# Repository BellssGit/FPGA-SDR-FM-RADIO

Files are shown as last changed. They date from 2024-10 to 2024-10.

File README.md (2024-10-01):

# FPGA-SDR-FM-RADIO
FPGA based FM radio with traditional IF architecture and digital IQ demodulation

[more detail (chinese only)](https://www.emoe.xyz/fpga_based_sdr_fm_radio/)

[demo video](https://www.bilibili.com/video/BV1SVxYeYEim/)

credit: https://github.com/alberto-grl/1bitSDR

Note； the PCB project name "R820T_With_LCMXO2" has nothing with R820T frontend IC, it was a thing when I start this PCB, but removed after few revisions.

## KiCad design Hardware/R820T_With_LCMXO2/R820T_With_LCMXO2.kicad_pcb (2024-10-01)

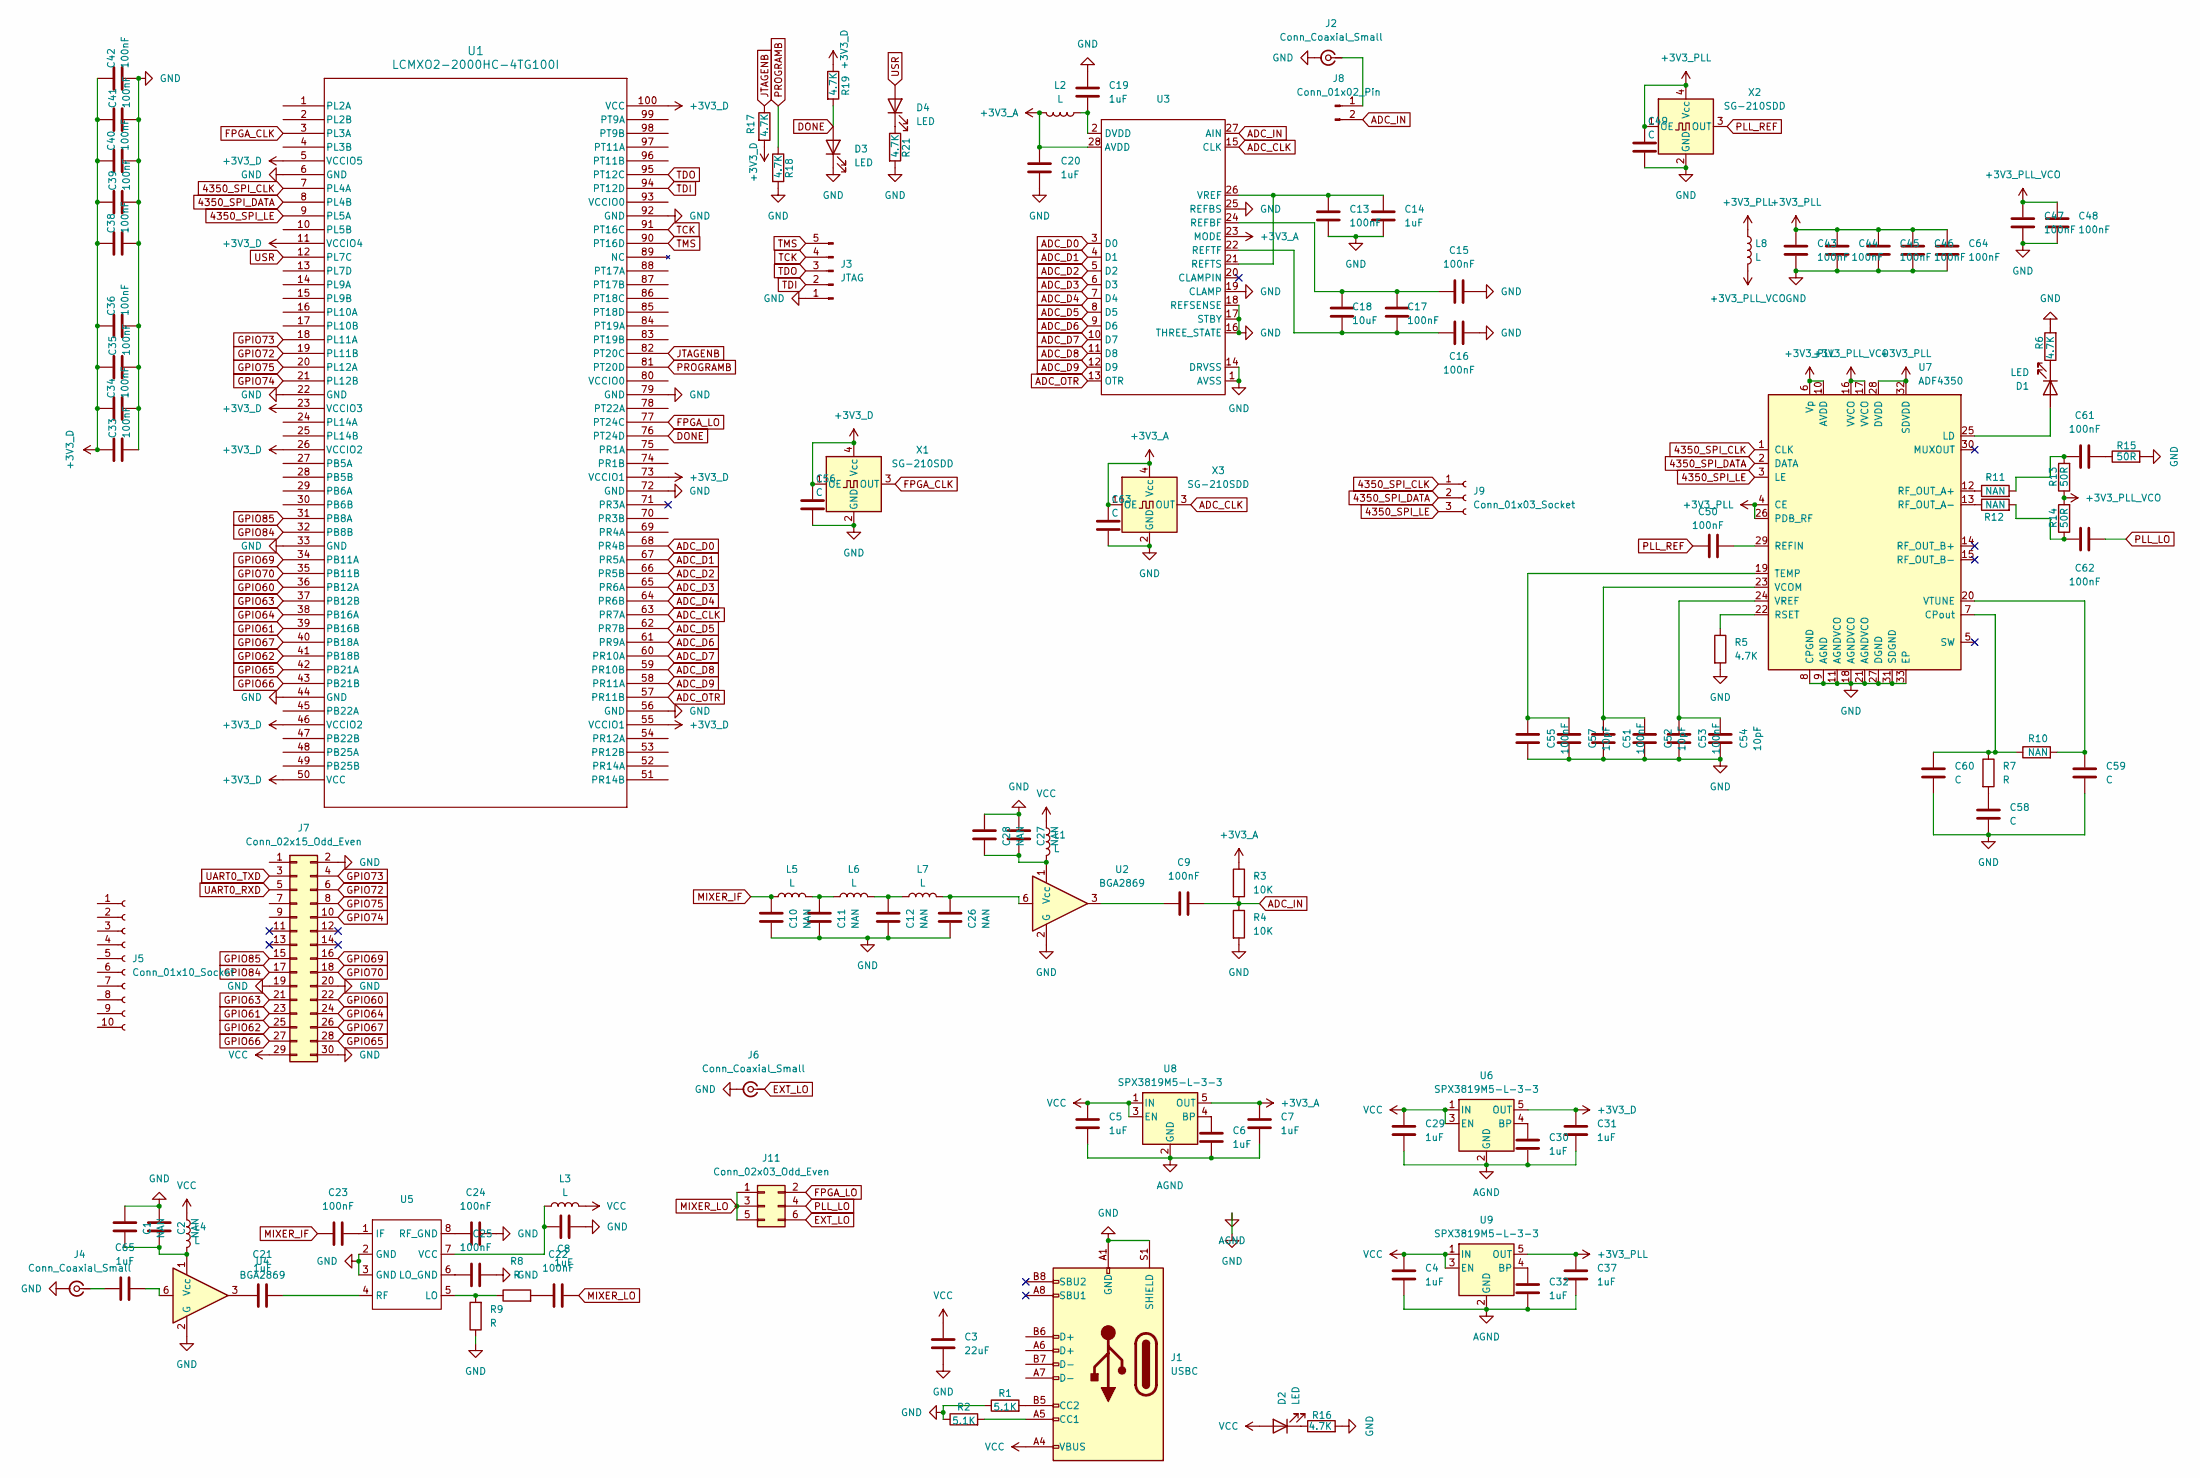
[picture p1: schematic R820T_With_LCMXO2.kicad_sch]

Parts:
C1, C2, C10, C11, C12, C26, C27, C28: NAN; C_0603_1608Metric
C3: 22uF; C_0805_2012Metric
C4, C5, C6, C7, C8, C14, C19, C20, C21, C29, C30, C31, C32, C37, C65: 1uF; C_0603_1608Metric
C9, C13, C15, C16, C17, C22, C23, C24, C25, C33, C34, C35, C36, C38, C39, C40, C41, C42, C43, C44, C45, C46, C47, C48, C50, C51, C53, C55, C61, C62, C64: 100nF; C_0603_1608Metric
C18: 10uF; C_0603_1608Metric
C49, C56, C58, C59, C60, C63: C; C_0603_1608Metric
C52, C54, C57: 10pF; C_0603_1608Metric
D1, D2, D3, D4: LED; LED_0603_1608Metric
J1: USBC; USB_C_Receptacle_G-Switch_GT-USB-7010ASV
J2, J4, J6: Conn_Coaxial_Small; SMA_Samtec_SMA-J-P-H-ST-EM1_EdgeMount_FIX_edge
J3: JTAG; PinSocket_1x05_P2.54mm_Vertical
J5: Conn_01x10_Socket; PinSocket_1x10_P2.54mm_Vertical
J7: Conn_02x15_Odd_Even; PinSocket_2x15_P2.54mm_Vertical
J8: Conn_01x02_Pin; PinHeader_1x02_P2.54mm_Vertical
J9: Conn_01x03_Socket; PinSocket_1x03_P2.54mm_Vertical
J11: Conn_02x03_Odd_Even; PinHeader_2x03_P2.54mm_Vertical
L1, L2, L3, L4, L8: L; L_0805_2012Metric
L5, L6, L7: L; L_0603_1608Metric
R1, R2: 5.1K; R_0603_1608Metric
R3, R4: 10K; R_0603_1608Metric
R5, R6, R16, R17, R18, R19, R21: 4.7K; R_0603_1608Metric
R7, R8, R9: R; R_0603_1608Metric
R10, R11, R12: NAN; R_0603_1608Metric
R13, R14, R15: 50R; R_0603_1608Metric
U1: LCMXO2-2000HC-4TG100I; TQFP-100_14x14mm_P0.5mm
U2, U4: BGA2869; SOT-363_SC-70-6
U3: SSOP-28_5.3x10.2mm_P0.65mm
U5: SO-8_3.9x4.9mm_P1.27mm
U6, U8, U9: SPX3819M5-L-3-3; SOT-23-5
U7: ADF4350; LFCSP-32-1EP_5x5mm_P0.5mm_EP3.25x3.25mm
X1, X2, X3: SG-210SDD; Oscillator_SMD_Abracon_ASE-4Pin_3.2x2.5mm

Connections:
4350_SPI_CLK: J9.1, U1.7 (PL4A), U7.1 (CLK)
4350_SPI_DATA: J9.2, U1.8 (PL4B), U7.2 (DATA)
4350_SPI_LE: J9.3, U1.9 (PL5A), U7.3 (LE)
+3V3_A: C7.1, C20.2, C63.1, L2.2, R3.1, U3.23 (MODE), U3.28 (AVDD), U8.5 (OUT), X3.1 (OE), X3.4 (Vcc)
+3V3_D: C31.1, C33.1, C34.1, C35.1, C36.1, C38.1, C39.1, C40.1, C41.1, C42.1, C56.1, R17.2, R19.1, U1.5 (VCCIO5), U1.11 (VCCIO4), U1.23 (VCCIO3), U1.26 (VCCIO2), U1.46 (VCCIO2), U1.50 (VCC), U1.55 (VCCIO1), U1.73 (VCCIO1), U1.100 (VCC), U6.5 (OUT), X1.1 (OE), X1.4 (Vcc)
+3V3_PLL: C37.1, C43.1, C44.1, C45.1, C46.1, C49.1, C64.1, L8.1, U7.4 (CE), U7.6 (Vp), U7.10 (AVDD), U7.26 (PDB_RF), U7.28 (DVDD), U7.32 (SDVDD), U9.5 (OUT), X2.1 (OE), X2.4 (Vcc)
+3V3_PLL_VCO: C47.1, C48.1, L8.2, R13.1, R14.2, U7.16 (VVCO), U7.17 (VVCO)
ADC_CLK: U1.63 (PR7A), U3.15 (CLK), X3.3 (OUT)
ADC_D0: U1.68 (PR4B), U3.3 (D0)
ADC_D1: U1.67 (PR5A), U3.4 (D1)
ADC_D2: U1.66 (PR5B), U3.5 (D2)
ADC_D3: U1.65 (PR6A), U3.6 (D3)
ADC_D4: U1.64 (PR6B), U3.7 (D4)
ADC_D5: U1.62 (PR7B), U3.8 (D5)
ADC_D6: U1.61 (PR9A), U3.9 (D6)
ADC_D7: U1.60 (PR10A), U3.10 (D7)
ADC_D8: U1.59 (PR10B), U3.11 (D8)
ADC_D9: U1.58 (PR11A), U3.12 (D9)
ADC_IN: C9.2, J8.2, R3.2, R4.1, U3.27 (AIN)
ADC_OTR: U1.57 (PR11B), U3.13 (OTR)
AGND: C1.2, C2.2, C3.2, C4.2, C5.2, C6.2, C7.2, C8.2, C10.1, C11.1, C12.1, C13.2, C14.2, C15.2, C16.2, C19.2, C20.1, C24.2, C25.2, C26.1, C27.2, C28.2, C29.2, C30.2, C31.2, C32.2, C33.2, C34.2, C35.2, C36.2, C37.2, C38.2, C39.2, C40.2, C41.2, C42.2, C43.2, C44.2, C45.2, C46.2, C47.2, C48.2, C49.2, C51.1, C52.1, C53.1, C54.1, C55.1, C56.2, C57.1, C58.2, C59.2, C60.2, C63.2, C64.2, D3.1 (K), J1.A1 (GND), J1.A12 (GND), J1.B1 (GND), J1.B12 (GND), J1.S1 (SHIELD), J2.2 (Ext), J3.1, J4.2 (Ext), J6.2 (Ext), J7.2, J7.19, J7.20, J7.30, R1.1, R2.1, R4.2, R5.2, R6.2, R9.1, R15.2, R16.2, R18.2, R21.2, U1.6 (GND), U1.22 (GND), U1.33 (GND), U1.44 (GND), U1.56 (GND), U1.72 (GND), U1.79 (GND), U1.92 (GND), U2.2 (G), U2.4 (G), U2.5 (G), U3.1 (AVSS), U3.14 (DRVSS), U3.16 (THREE_STATE), U3.17 (STBY), U3.18 (REFSENSE), U3.19 (CLAMP), U3.25 (REFBS), U4.2 (G), U4.4 (G), U4.5 (G), U5.2 (GND), U5.3 (GND), U6.2 (GND), U7.8 (CPGND), U7.9 (AGND), U7.11 (AGNDVCO), U7.18 (AGNDVCO), U7.21 (AGNDVCO), U7.27 (DGND), U7.31 (SDGND), U7.33 (EP), U8.2 (GND), U9.2 (GND), X1.2 (GND), X2.2 (GND), X3.2 (GND)
DONE: D3.2 (A), R19.2, U1.76 (PT24D)
EXT_LO: J6.1 (In), J11.6
FPGA_CLK: U1.3 (PL3A), X1.3 (OUT)
FPGA_LO: J11.2, U1.77 (PT24C)
GPIO60: J7.22, U1.36 (PB12A)
GPIO61: J7.23, U1.39 (PB16B)
GPIO62: J7.25, U1.41 (PB18B)
GPIO63: J7.21, U1.37 (PB12B)
GPIO64: J7.24, U1.38 (PB16A)
GPIO65: J7.28, U1.42 (PB21A)
GPIO66: J7.27, U1.43 (PB21B)
GPIO67: J7.26, U1.40 (PB18A)
GPIO69: J7.16, U1.34 (PB11A)
GPIO70: J7.18, U1.35 (PB11B)
GPIO72: J7.6, U1.19 (PL11B)
GPIO73: J7.4, U1.18 (PL11A)
GPIO74: J7.10, U1.21 (PL12B)
GPIO75: J7.8, U1.20 (PL12A)
GPIO84: J7.17, U1.32 (PB8B)
GPIO85: J7.15, U1.31 (PB8A)
JTAGENB: R17.1, U1.82 (PT20C)
MIXER_IF: C10.2, C23.1, L5.1
MIXER_LO: C22.2, J11.1, J11.3, J11.5
unnamed: C9.1, U2.3
unnamed: C11.2, L5.2, L6.1
unnamed: C12.2, L6.2, L7.1
unnamed: C21.1, U4.3
unnamed: C22.1, R8.2
unnamed: C26.2, L7.2, U2.6
unnamed: C58.1, R7.2
unnamed: C61.1, R11.2, R13.2
unnamed: C61.2, R15.1
unnamed: C62.1, R12.2, R14.1
unnamed: C65.2, U4.6
unnamed: D1.2 (A), U7.25 (LD)
unnamed: D1.1 (K), R6.1
unnamed: D2.1 (K), R16.1
unnamed: D4.1 (K), R21.1
unnamed: J1.A5 (CC1), R2.2
unnamed: J1.B5 (CC2), R1.2
unnamed: J2.1 (In), J8.1
unnamed: C65.1, J4.1 (In)
unnamed: C27.1, C28.1, L1.2, U2.1 (Vcc)
unnamed: C19.1, L2.1, U3.2 (DVDD)
unnamed: C15.1, C17.2, C18.2, U3.24 (REFBF)
unnamed: C16.1, C17.1, C18.1, U3.22 (REFTF)
unnamed: C13.1, C14.1, U3.21 (REFTS), U3.26 (VREF)
unnamed: C1.1, C2.1, L4.2, U4.1 (Vcc)
unnamed: C23.2, U5.1 (IF)
unnamed: R8.1, R9.2, U5.5 (LO)
unnamed: C25.1, U5.6 (LO_GND)
unnamed: C21.2, U5.4 (RF)
unnamed: C24.1, U5.8 (RF_GND)
unnamed: C8.1, L3.1, U5.7 (VCC)
unnamed: C30.1, U6.4 (BP)
unnamed: C60.1, R7.1, R10.1, U7.7 (CPout)
unnamed: C50.2, U7.29 (REFIN)
unnamed: R11.1, U7.12 (RF_OUT_A+)
unnamed: R12.1, U7.13 (RF_OUT_A-)
unnamed: R5.1, U7.22 (RSET)
unnamed: C55.2, C57.2, U7.19 (TEMP)
unnamed: C51.2, C52.2, U7.23 (VCOM)
unnamed: C53.2, C54.2, U7.24 (VREF)
unnamed: C59.1, R10.2, U7.20 (VTUNE)
unnamed: C6.1, U8.4 (BP)
unnamed: C32.1, U9.4 (BP)
PLL_LO: C62.2, J11.4
PLL_REF: C50.1, X2.3 (OUT)
PROGRAMB: R18.1, U1.81 (PT20D)
TCK: J3.4, U1.91 (PT16C)
TDI: J3.2, U1.94 (PT12D)
TDO: J3.3, U1.95 (PT12C)
TMS: J3.5, U1.90 (PT16D)
UART0_RXD: J7.5
UART0_TXD: J7.3
USR: D4.2 (A), U1.12 (PL7C)
VCC: C3.1, C4.1, C5.1, C29.1, D2.2 (A), J1.A4 (VBUS), J1.A9 (VBUS), J1.B4 (VBUS), J1.B9 (VBUS), J7.29, L1.1, L3.2, L4.1, U6.1 (IN), U6.3 (EN), U8.1 (IN), U8.3 (EN), U9.1 (IN), U9.3 (EN)

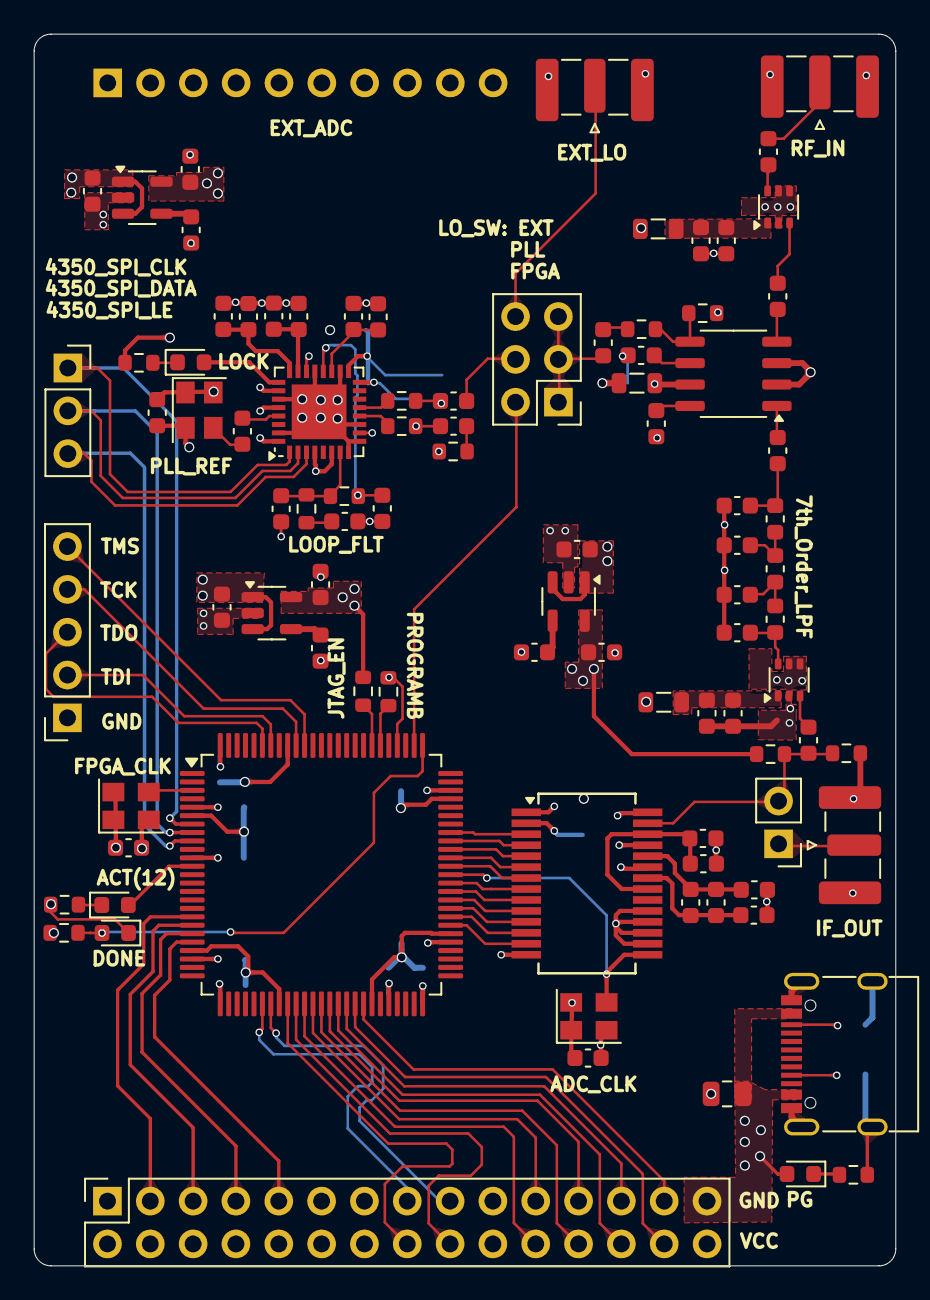
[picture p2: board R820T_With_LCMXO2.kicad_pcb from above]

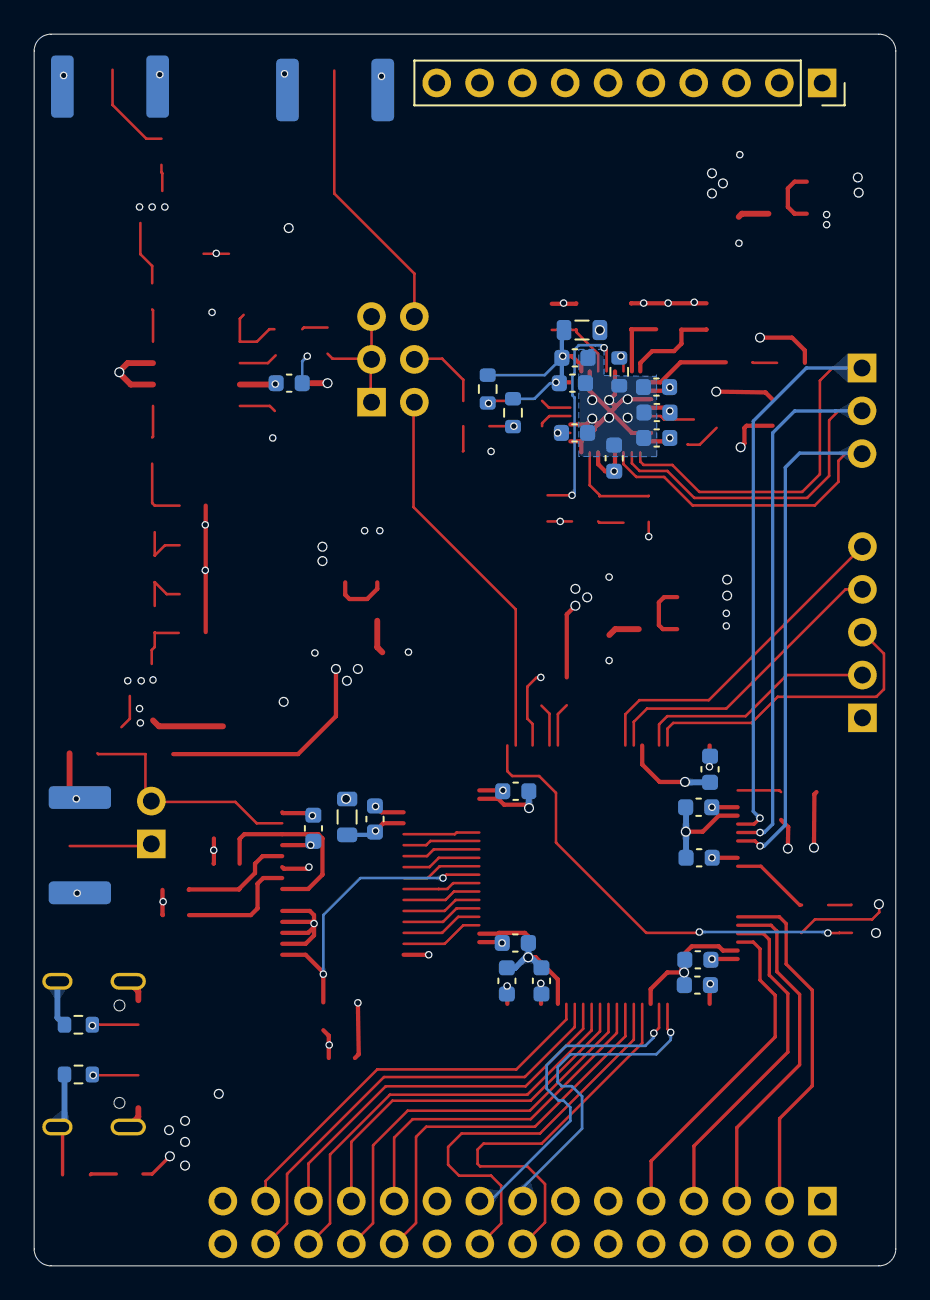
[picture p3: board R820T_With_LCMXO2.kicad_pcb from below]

Board: 4 copper layers, 51.1 x 73.0 mm, 119 parts (27 on the bottom side), 96 nets.
